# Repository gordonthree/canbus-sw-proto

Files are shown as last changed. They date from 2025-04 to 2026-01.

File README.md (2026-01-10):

# CAN bus switch prototype

Some circuit board sketches in the free version of EagleCad

## Brain board
* Raspberry Pi 3 or 4?
* Touchscreen usb + hdmi
* CAN bus to SPI shield
* Web based interface

## Alt brain board
* 1x ESP32
* 1x CAN bus transciever
* 1x 4-pos screw terminal for power + can
* 

## Demo 01 - Single switch with STM32 and CANBUS
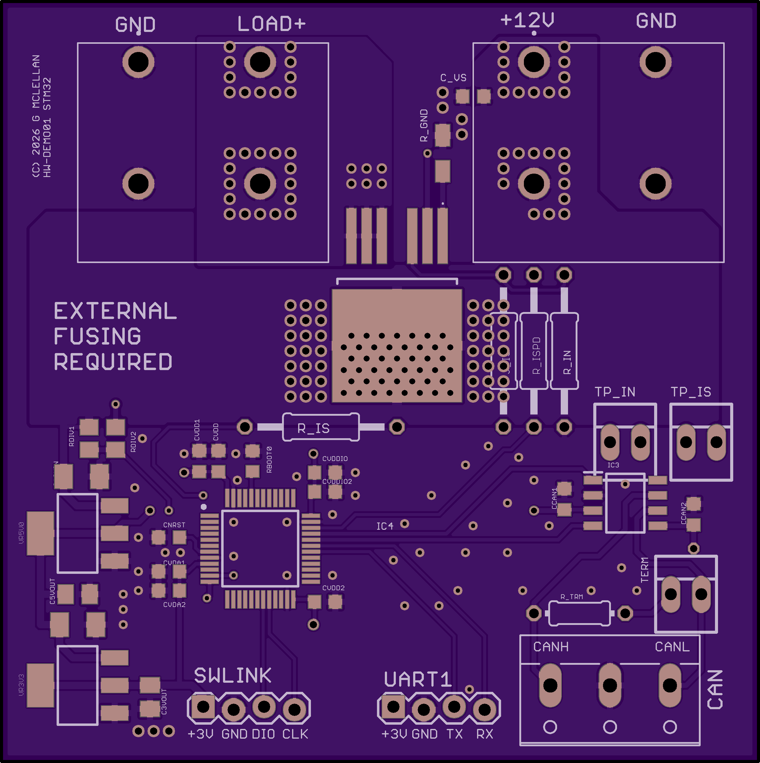
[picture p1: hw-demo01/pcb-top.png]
PCB rendering
* <br>
* 1x STM32F042
* 1x Isolated CAN bus transciever
* 1x Infineon BTS50010-1TAD PROFet Smart High Side Switch
* Voltage monitoring via resistor divider
* Current monitoring via Smart Switch
* Onboard 3v3 and 5v linear regulators
* Headers for SWLINK and UART
* Wago style screw terminal connector for 2-wire + drain CANBUS cable
* High current terminal block style battery input and load output
  
## Demo 02 - Single switch 
* 1x Infineon BTS50010-1TAD PROFet Smart High Side Switch
* Voltage monitoring via resistor divider
* Current monitoring via Smart Switch
* Header for control connection to microcontroller
* High current terminal block style battery input and load output

## Demo 03 - Dual switch with STM32 and CANBUS
* 1x STM32F042
* 1x Isolated CAN bus transciever
* 2x Infineon BTS50010-1TAD PROFet Smart High Side Switch
* Voltage monitoring via resistor divider
* Current monitoring via Smart Switch
* Onboard 3v3 and 5v linear regulators
* Headers for SWLINK and UART
* Wago style screw terminal connector for 2-wire + drain CANBUS cable
* High current terminal block style battery input and load output
  
## Prototype 01 Four switches
* 1x ESP32
* 1x CAN bus transciever
* 2x p-channel FETs (20a max?)
* 2x high side switch ICs (10a max?)
* 1x dual chan driver TC4472
* 1x 6-pos barrier strip V+ GND SW1 SW2 SW3 SW4
* 1x 3-pos terminal for can bus
* 1x serial programming header

## Prototype 02 Three switches
* 1x ESP32
* 1x CAN bus transciever
* 2x p-channel FETs (30a max?) power-so8
* 1x high side switch ICs (10a max?)
* 1x dual chan driver TC4472
* 1x 6-pos barrier strip V+ V+ SW1 SW2 SW3 GND
* 1x 3-pos terminal for can bus
* 1x serial programming header
  
## Prototype 03 Six switch
* 1x ESP32
* 1x CAN bus transciever
* 4x p-channel FETs (30a max?) power-so8
* 2x high side switch ICs (10a max?)
* 1x dual chan driver TC4472
* 1x 3-pos barrier strip for power +12 +12 GND
* 2x 6-pos barrier strip SW1 GND SW2 GND SW3 GND - repeated for other side
* 1x 3-pos terminal for can bus
* 1x serial programming header

## Prototype 04 Three switches with STM32
* 1x STM32F042C6
* 1x CAN bus transciever
* 2x p-channel FETs (30a max?) power-so8
* 1x high side switch ICs (10a max?)
* 1x dual chan driver TC4472
* 1x 6-pos barrier strip V+ V+ SW1 SW2 SW3 GND
* 1x 3-pos terminal for can bus
* 1x serial programming header
 
## Minimum interconnect for nodes
* 2-pair cable with drain
* first pair for CANH-IN and CANL-IN
* second pair for CANH-OUT and CANL-OUT
* drain is grounded at controller / hub

## Ideal interconnect for nodes
* 4-pair cable with drain
* first pair for CANH-IN and CANL-IN
* second and fourth pair for +VBAT and ground
* third pair for CANH-OUT and CANL-OUT
* drain is grounded at controller / hub

## CAN Hub
* eight total de9 connectors, one input, one output, six spurs
* each spur is wired in series, with Cx-IN and Cx-OUT daisy chained
* spurs that are not connected have a shorting plug installed connecting Cx-IN to Cx-OUT

## Parts
* 4x8 RGB matrix keypad https://www.adafruit.com/product/4020
* high side switch (ssr) https://mou.sr/4jcK616
* 6 position terminal block https://mou.sr/4i4P92Y
* heavy duty 6-pos terminal https://mou.sr/3R63QYn
* heavy duty 3-pos terminal block https://mou.sr/3FTFHBW
* ATO fuse holder https://mou.sr/4cihwsZ
* CANBUS Transceiver MCP2562T https://mou.sr/4llTLVa 
* ESP32 Module https://mou.sr/4j1XWDP
* Onboard DC-DC converter https://mou.sr/4i8eVTN
* P chan fet chonky https://mou.sr/42aUOja
* P chan power-so8 https://mou.sr/42BhcBs
* 3.3v LDO regulator https://mou.sr/3RgIUy6
* 20 awg shielded twisted pair cable https://a.co/d/8FQRYBL
* Texas Inst mosfet driver 5a inverted dual-ch SO8 https://mou.sr/3YqDYuk
* STM32 Micro with CAN bus 20 pin ssop https://mou.sr/4jwf9Fx
* ESP32 WROOM module with antenna https://mou.sr/3XWw2kl
* STM32 Dev Board using inexepensive mcu https://www.digikey.com/short/59jq87v5
* STM32 48-pin QFP STM32F042C6T7 https://mou.sr/3Eqjfjx
* DC-DC Switching regulator TPS560430 automotive 5v output https://mou.sr/4cZ1YLn
* DC-DC Sync-switching regulator LMR51625 automotive adjustable output https://mou.sr/4ipTHB4

## remote node introductions
* 10 seconds after boot remote nodes will start sending introduction messages 0x7XX
  * master will record message id and node id for each device
  * master will compare node id with database of known nodes
  * nodes that are already known will have their last-seen timestamp updated
  * newly introduced nodes will be added to the database, recording their first-seen timestamp
  * master will respond with 0x401 to the node to acknowledge introduction
  * after reciving 0x401 the remote node will clear the introduction flag and enter normal operation
* after no introductions the master will enumerate new nodes
  * master will send 0x402:0x40A to the remote node and nodes will respond with 0x710:0x74F for each module the node offers
  * modules will be recorded in database using unique 32-bit node ID and 16-bit module ID
  * master will send 0x401 to the remote node after recording each module 
* after introductions and enumeration master will review database of nodes
  * nodes with a timestamp older than the current boot timestamp will be marked as not-present
    * master will send 0x40C node check message to the node
    * if remote node responds with their node id, update last seen, flag for enumeration 
    * if remote node does not respond mark the node missing in the database and alert user

## normal operation
* after introduction and enumeration are complete master will send 0x10A indicating nodes should begin normal operation
* nodes start sending 0x5XX data messages at the configured rates

## request info flag
* master will instruct display module to request info, providing a message id
* display module will watch for the message id and receive 8 bytes of data

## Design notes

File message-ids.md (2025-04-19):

# CAN Bus Message IDs

Borrowed from [Kvaser](https://kvaser.com/can-protocol-tutorial/)
> ### A note on the Identifier Values
> We said that 11 (CAN 2.0A) or 29 (CAN 2.0B) bits is available in the Identifier. This is not entirely correct. Due to compability with a certain old CAN controller (guess which?), identifiers must not have the 7 most significant bits set to all ones, so only the identifiers 0..2031 are left for the 11-bit identifiers, and the user of 29-bit identifiers can use 532676608 different values. Note that all other CAN controllers accept the “illegal” identifiers, so in a modern CAN system identifiers 2032..2047 can be used without restrictions.

## We've moved
I'll make the link public readable eventually
* https://docs.google.com/spreadsheets/d/1QVM61p1eubtlPMyJ19RLGeI64S9uRlPBL7KCpJWwj3g/edit?gid=0#gid=0
  
### Notes
* https://docs.google.com/spreadsheets/d/1eirT8LbSRl4j06BpwgsiE4PM_2BGH9UStdWLXwKvHJw/edit?gid=10#gid=10

### Example
```
// Constants for specific message IDs (example)
#define ENGINE_TEMP_ID 0x100
#define VEHICLE_SPEED_ID 0x200
#define BATTERY_VOLTAGE_ID 0x300
```

Outdated info below.
## Priority 0 (should these be error frames?)
* 0x100: Over current
     * D0-D3: Device ID (unique)
     * D4-D5: Measured current 16-bits
* 0x110: Over temperature
     * D0-D3: Device ID (unique)
     * D4-D5: Measured temperature 16-bits
* 0x120: Over voltage
     * D0-D3: Device ID (unique)
     * D4-D5: Measured voltage 16-bits

## Priority 1
* 0x1A0: Set output switch state (on, off)
    * Bytes 0-3: Device ID (unique)
    * Byte 5: Switch number
    * Byte 6: Switch state
* 0x1B0: Set output switch mode (steady, blink, strobe, etc)
    * Bytes 0-3: Device ID (unique)
    * Byte 5: Switch number
    * Byte 6: Switch mode

## Priority 2
* 0x200: 

## Priority 3
* 0x300: 

## Priority 4
* 0x400:

## Priority 5
* 0x500:

## Priority 6
* 0x600:

## Priority 7
* 0x700: Device introduction
    * Bytes 0-3: Device ID (unique)
    * Byte 5: Device type (output switch, button panel, display, etc)
    * Byte 6: Device specific count (switches, buttons, etc)

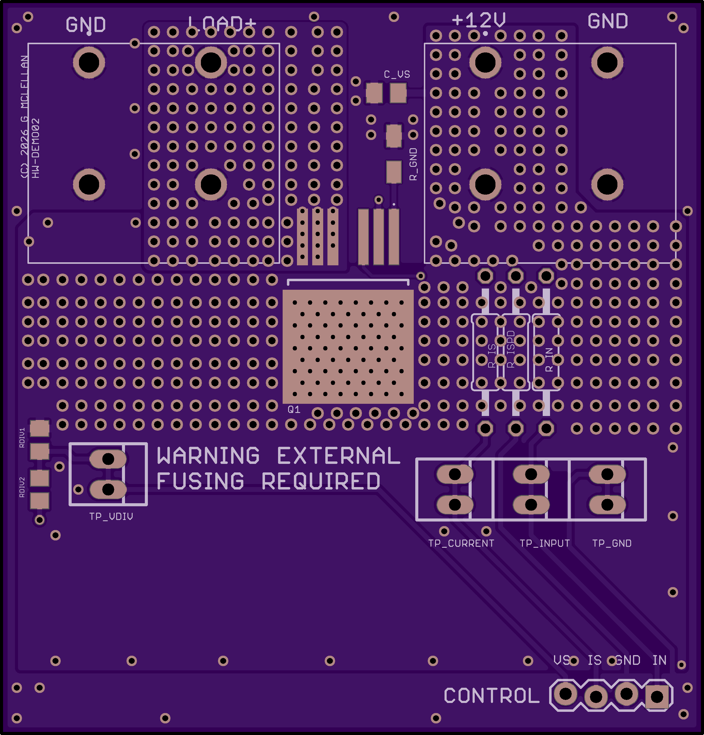
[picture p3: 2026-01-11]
hw-demo02/pcb-top-render-demo02.png

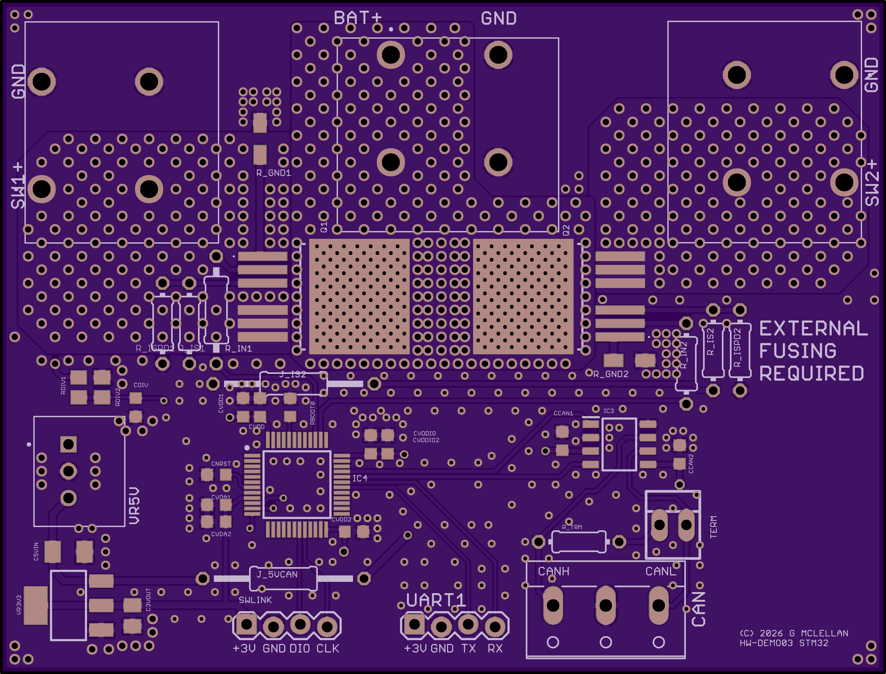
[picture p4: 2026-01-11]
hw-demo03/demo03-pcb-top.png

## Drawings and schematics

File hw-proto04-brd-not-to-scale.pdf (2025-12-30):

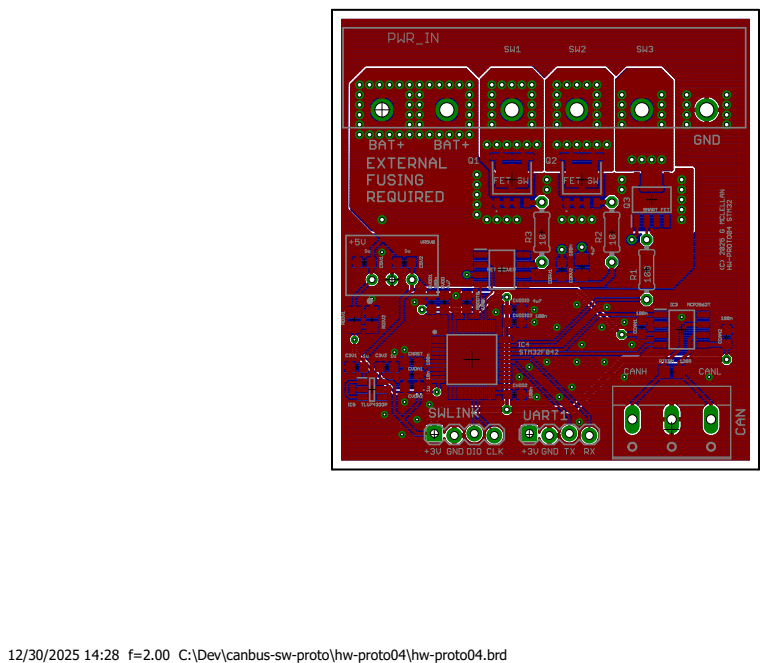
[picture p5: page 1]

12/30/2025 14:28 f=2.00 C:\Dev\canbus-sw-proto\hw-proto04\hw-proto04.brd

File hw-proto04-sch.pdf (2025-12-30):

A

A

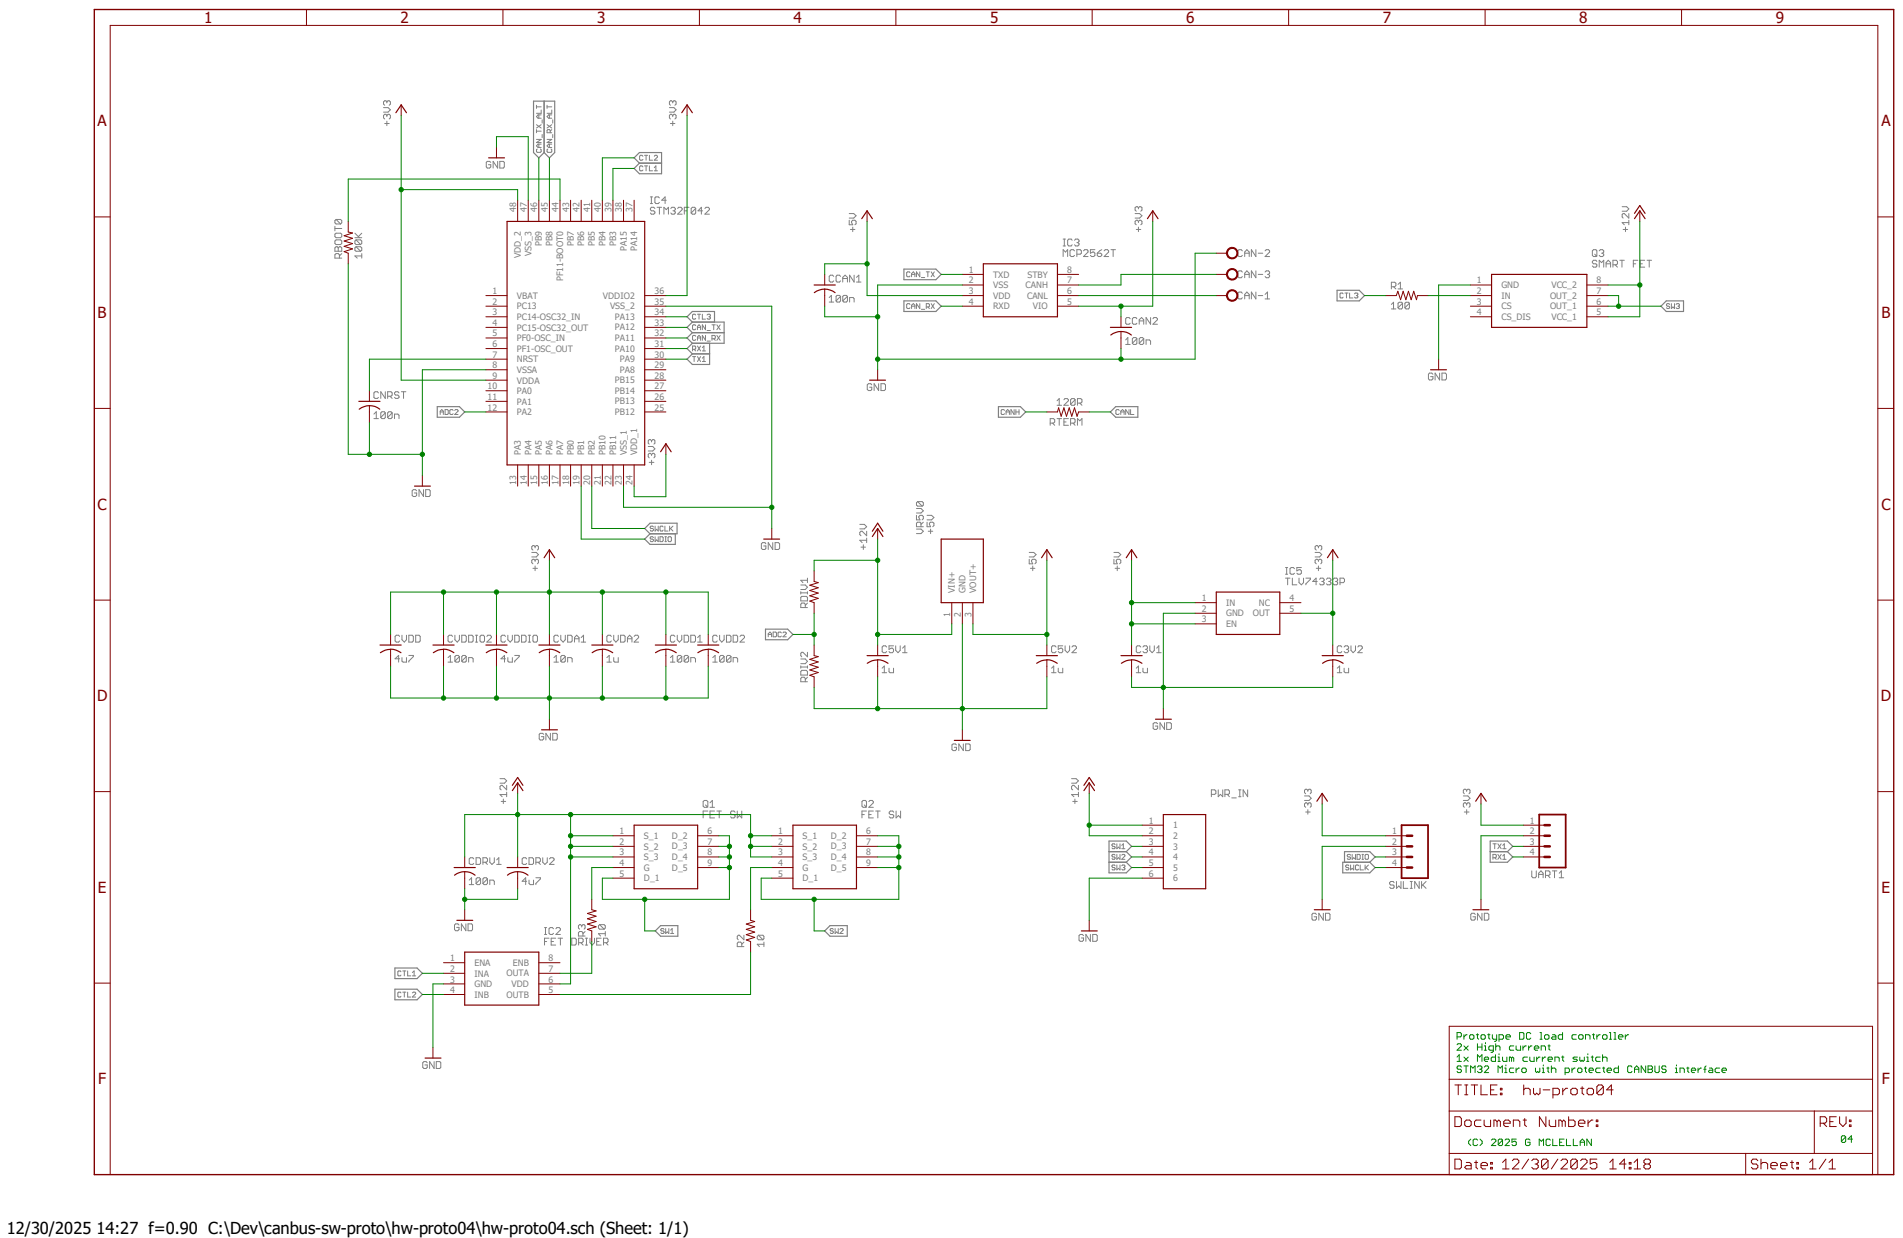
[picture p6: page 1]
GND 1; CS_DIS 4; VCC_2; 8 OUT_2; 7 OUT_1; 6 VCC_1; 5 TXD 1; VSS 2; VDD 3; RXD 4; STBY; 8 CANH; 7 CANL; 6 VIO; 6 VIN+ 1 GND; 2 VOUT+; 9 ENA 1; INA 2; GND 3; INB 4; ENB; 8 OUTA; 7 VDD; 6 OUTB; VBAT 1; PC14-OSC32_IN 3; PC15-OSC32_OUT 4; PF0-OSC_IN 5; PF1-OSC_OUT 6; NRST 7; VSSA 8; VDDA 9; PA³ 13 PA⁴ 14 PA⁵ 15 PA⁶ 16 PA⁷ 17 PB0 18 PB1 19 PB2 20 PB10 21 PB11 22 VSS_1 23 VDD_1 24 VDDIO2; 36 VSS_2; 25 VDD_2 48 VSS_3 47 PB9 46 PB8 45 PF11⁻BOOT0 44 PB7 43 PB6 42 PB5 41 PB4 40 PB3 39 PA¹⁵ ³⁸ PA¹⁴ ³⁷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

12/30/2025 14:27 f=0.90 C:\Dev\canbus-sw-proto\hw-proto04\hw-proto04.sch (Sheet: 1/1)

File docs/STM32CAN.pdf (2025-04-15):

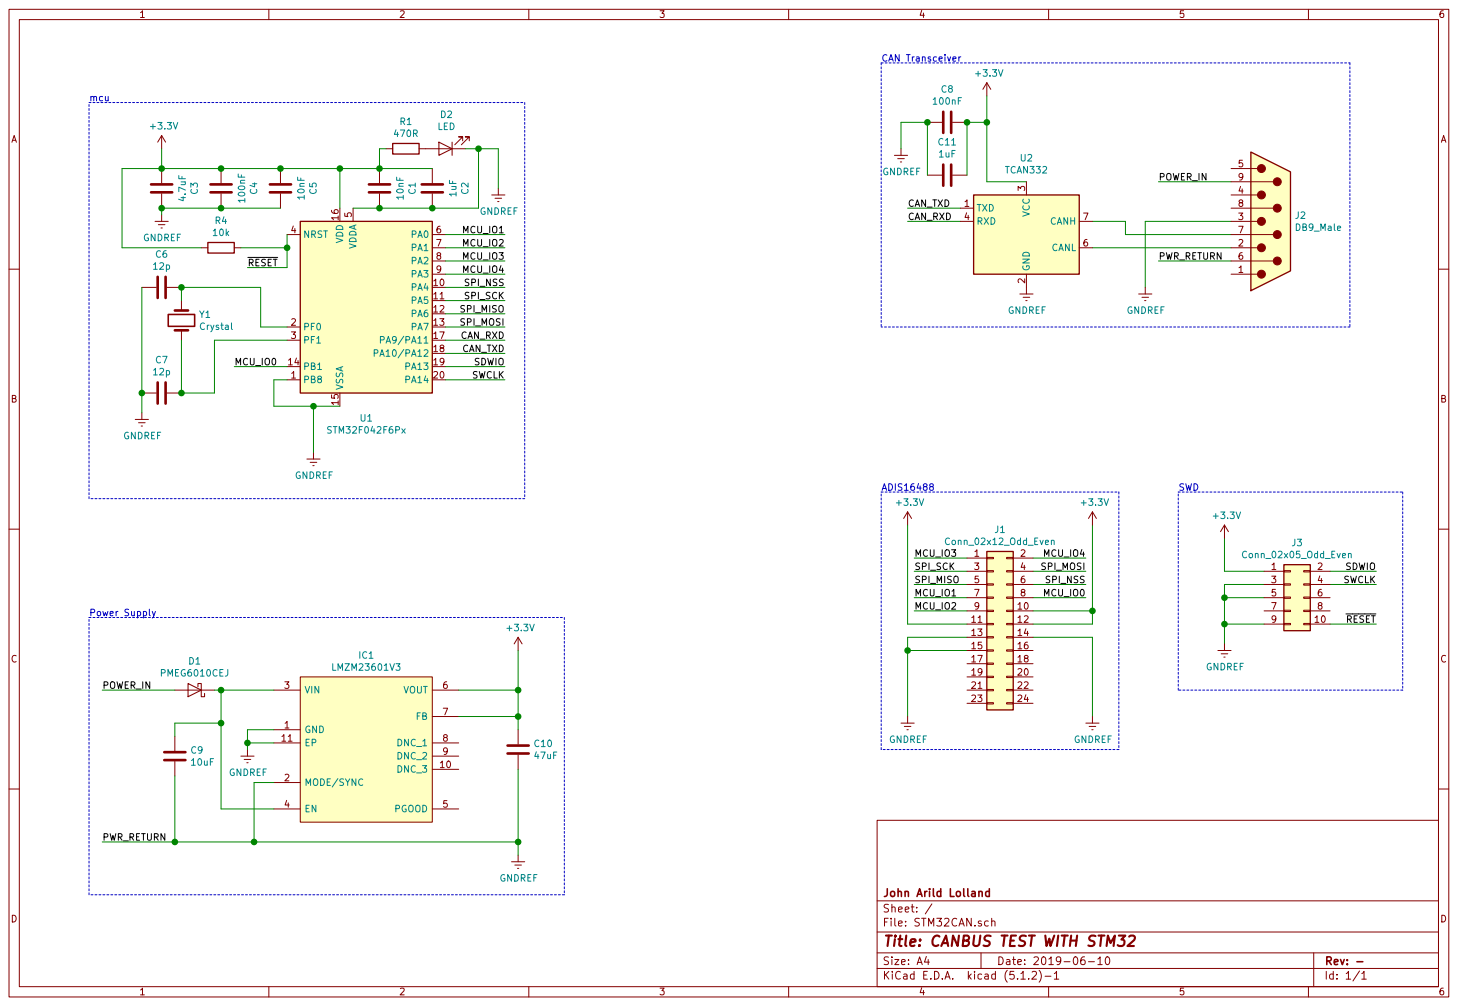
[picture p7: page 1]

3 RXD 4 CANL 6 CANH 7 U2 TCAN332 SWD

File: STM32CAN.sch Sheet: / John Arild Lolland

Id: 1/1 Title: CANBUS TEST WITH STM32

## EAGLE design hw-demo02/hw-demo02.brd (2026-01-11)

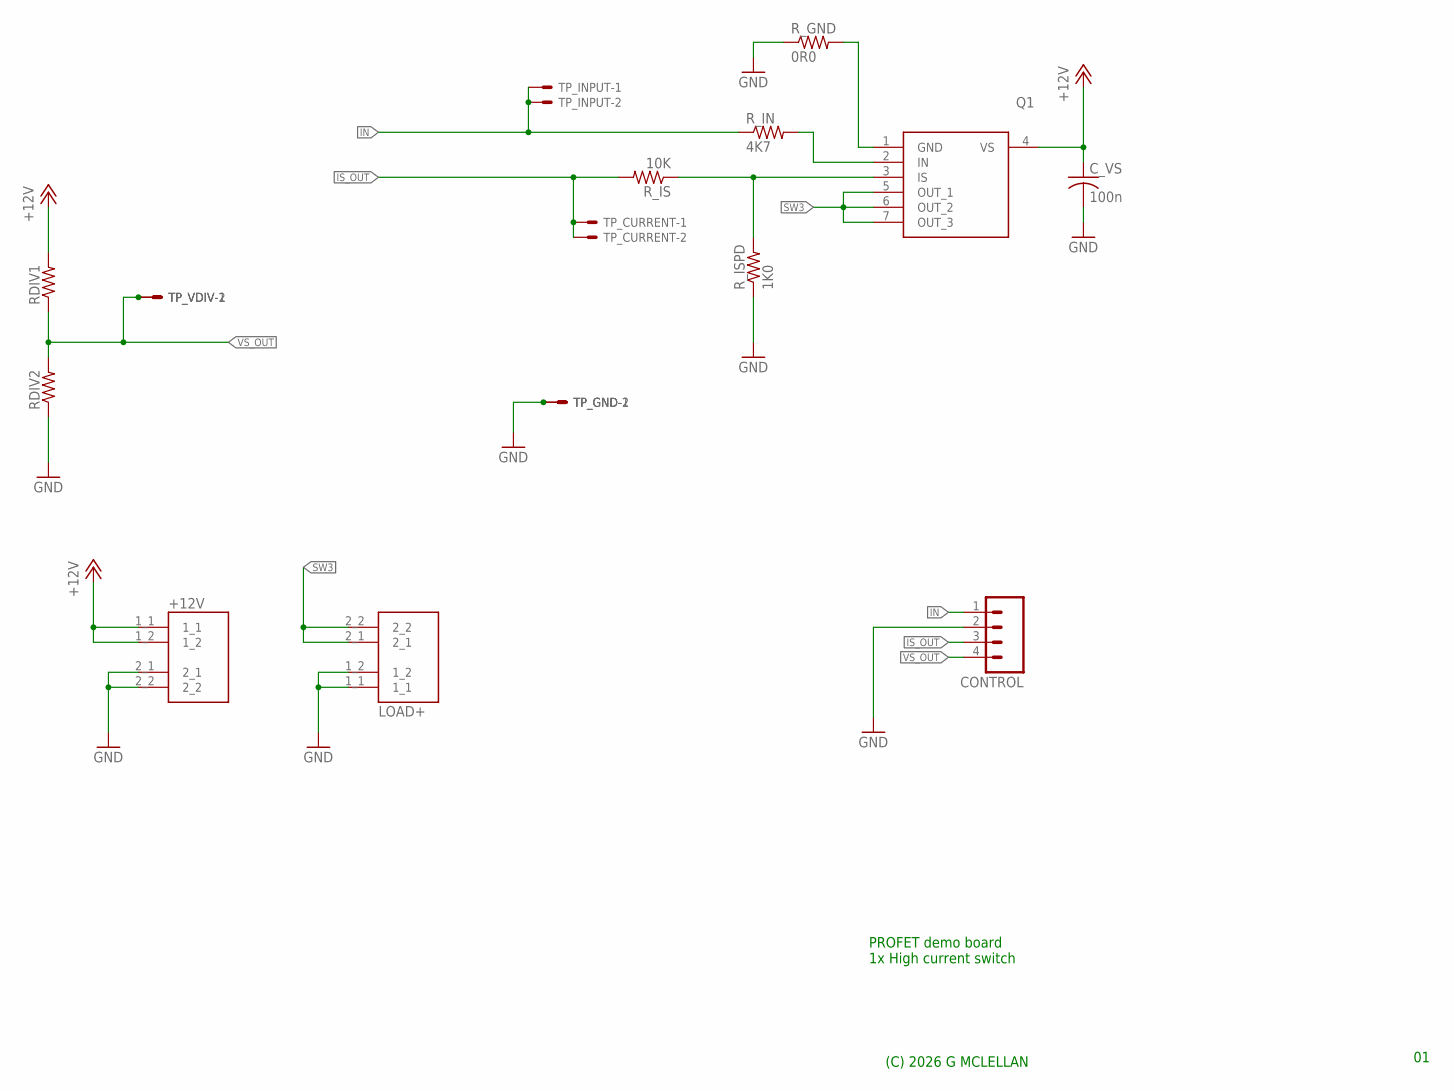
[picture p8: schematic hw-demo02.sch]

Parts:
+12V: VP0265840000G; AMPHENOL_VP0265840000G
CONTROL: M04LOCK; 1X04_LOCK
C_VS: 100n; C0805K
LOAD+: VP0265840000G; AMPHENOL_VP0265840000G
Q1: BTS500101TADATMA2
RDIV1, RDIV2: R-US_R0805; R0805
R_GND: 0R0; R1206W
R_IN: 4K7; 0207/12
R_IS: 10K; 0207/12
R_ISPD: 1K0; 0207/12
TP_CURRENT: 22-23-2021
TP_GND: 22-23-2021
TP_INPUT: 22-23-2021
TP_VDIV: 22-23-2021

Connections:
+12V: +12V.1_1, +12V.1_2, C_VS.1, Q1.4 (VS), RDIV1.2
CTL3`: Q1.2 (IN), R_IN.2
GND: +12V.2_1, +12V.2_2, CONTROL.2, C_VS.2, LOAD+.1_1, LOAD+.1_2, RDIV2.1, R_GND.1, R_ISPD.1, TP_GND.1, TP_GND.2
IN: CONTROL.1, R_IN.1, TP_INPUT.1, TP_INPUT.2
IS: Q1.3 (IS), R_IS.1, R_ISPD.2
IS_OUT: CONTROL.3, R_IS.2, TP_CURRENT.1, TP_CURRENT.2
unnamed: Q1.1 (GND), R_GND.2
SW3: LOAD+.2_1, LOAD+.2_2, Q1.5 (OUT_1), Q1.6 (OUT_2), Q1.7 (OUT_3)
VS_OUT: CONTROL.4, RDIV1.1, RDIV2.2, TP_VDIV.1, TP_VDIV.2

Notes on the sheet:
PROFET demo board 1x High current switch
(C) 2026 G MCLELLAN

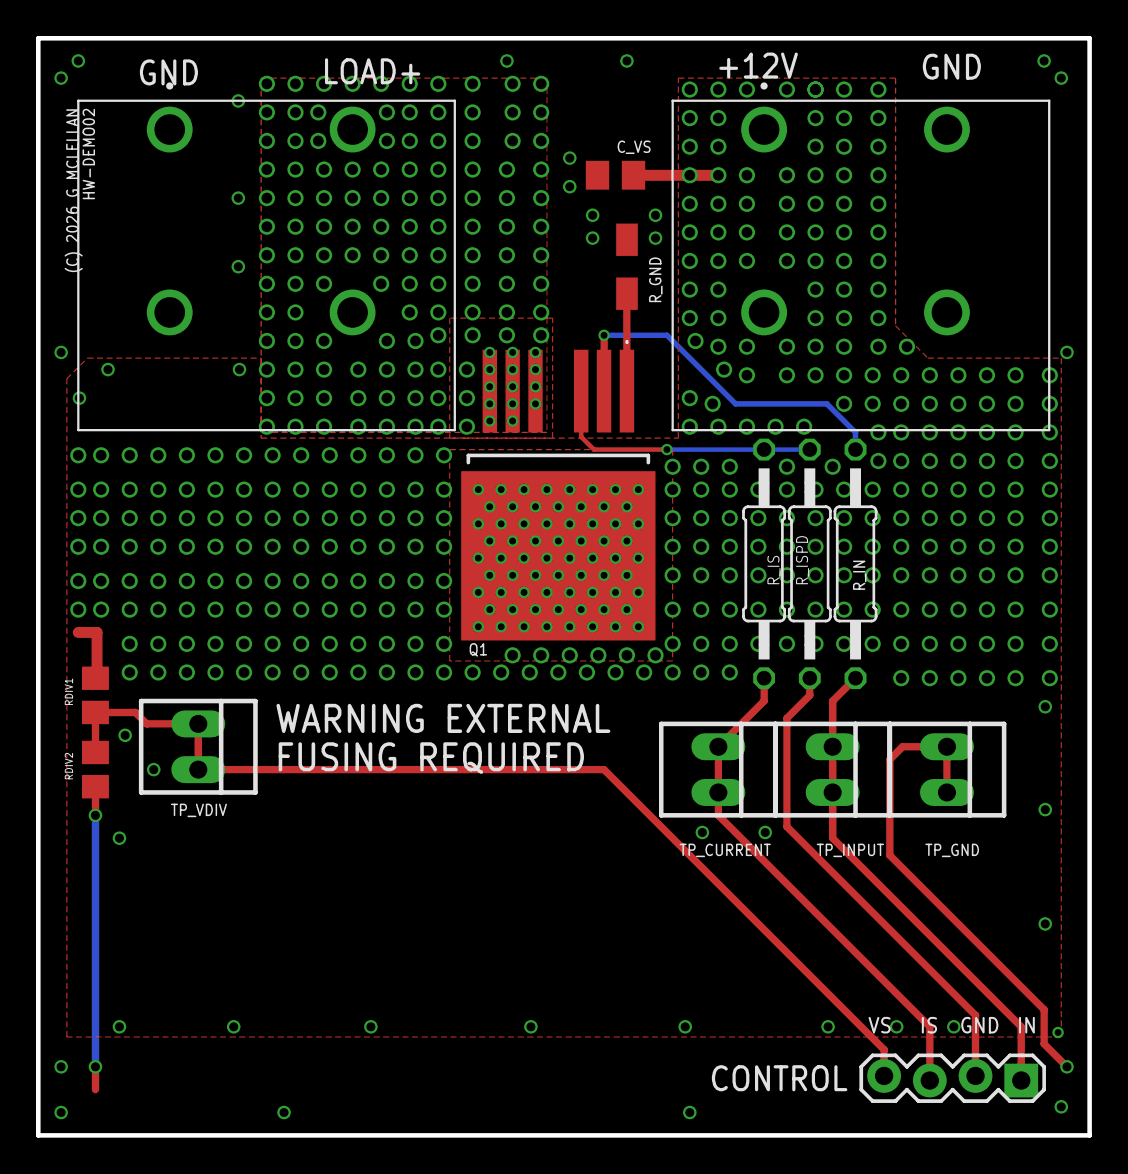
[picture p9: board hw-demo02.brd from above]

Board: 2 copper layers, 58.4 x 61.0 mm, 15 parts (0 on the bottom side), 9 nets.

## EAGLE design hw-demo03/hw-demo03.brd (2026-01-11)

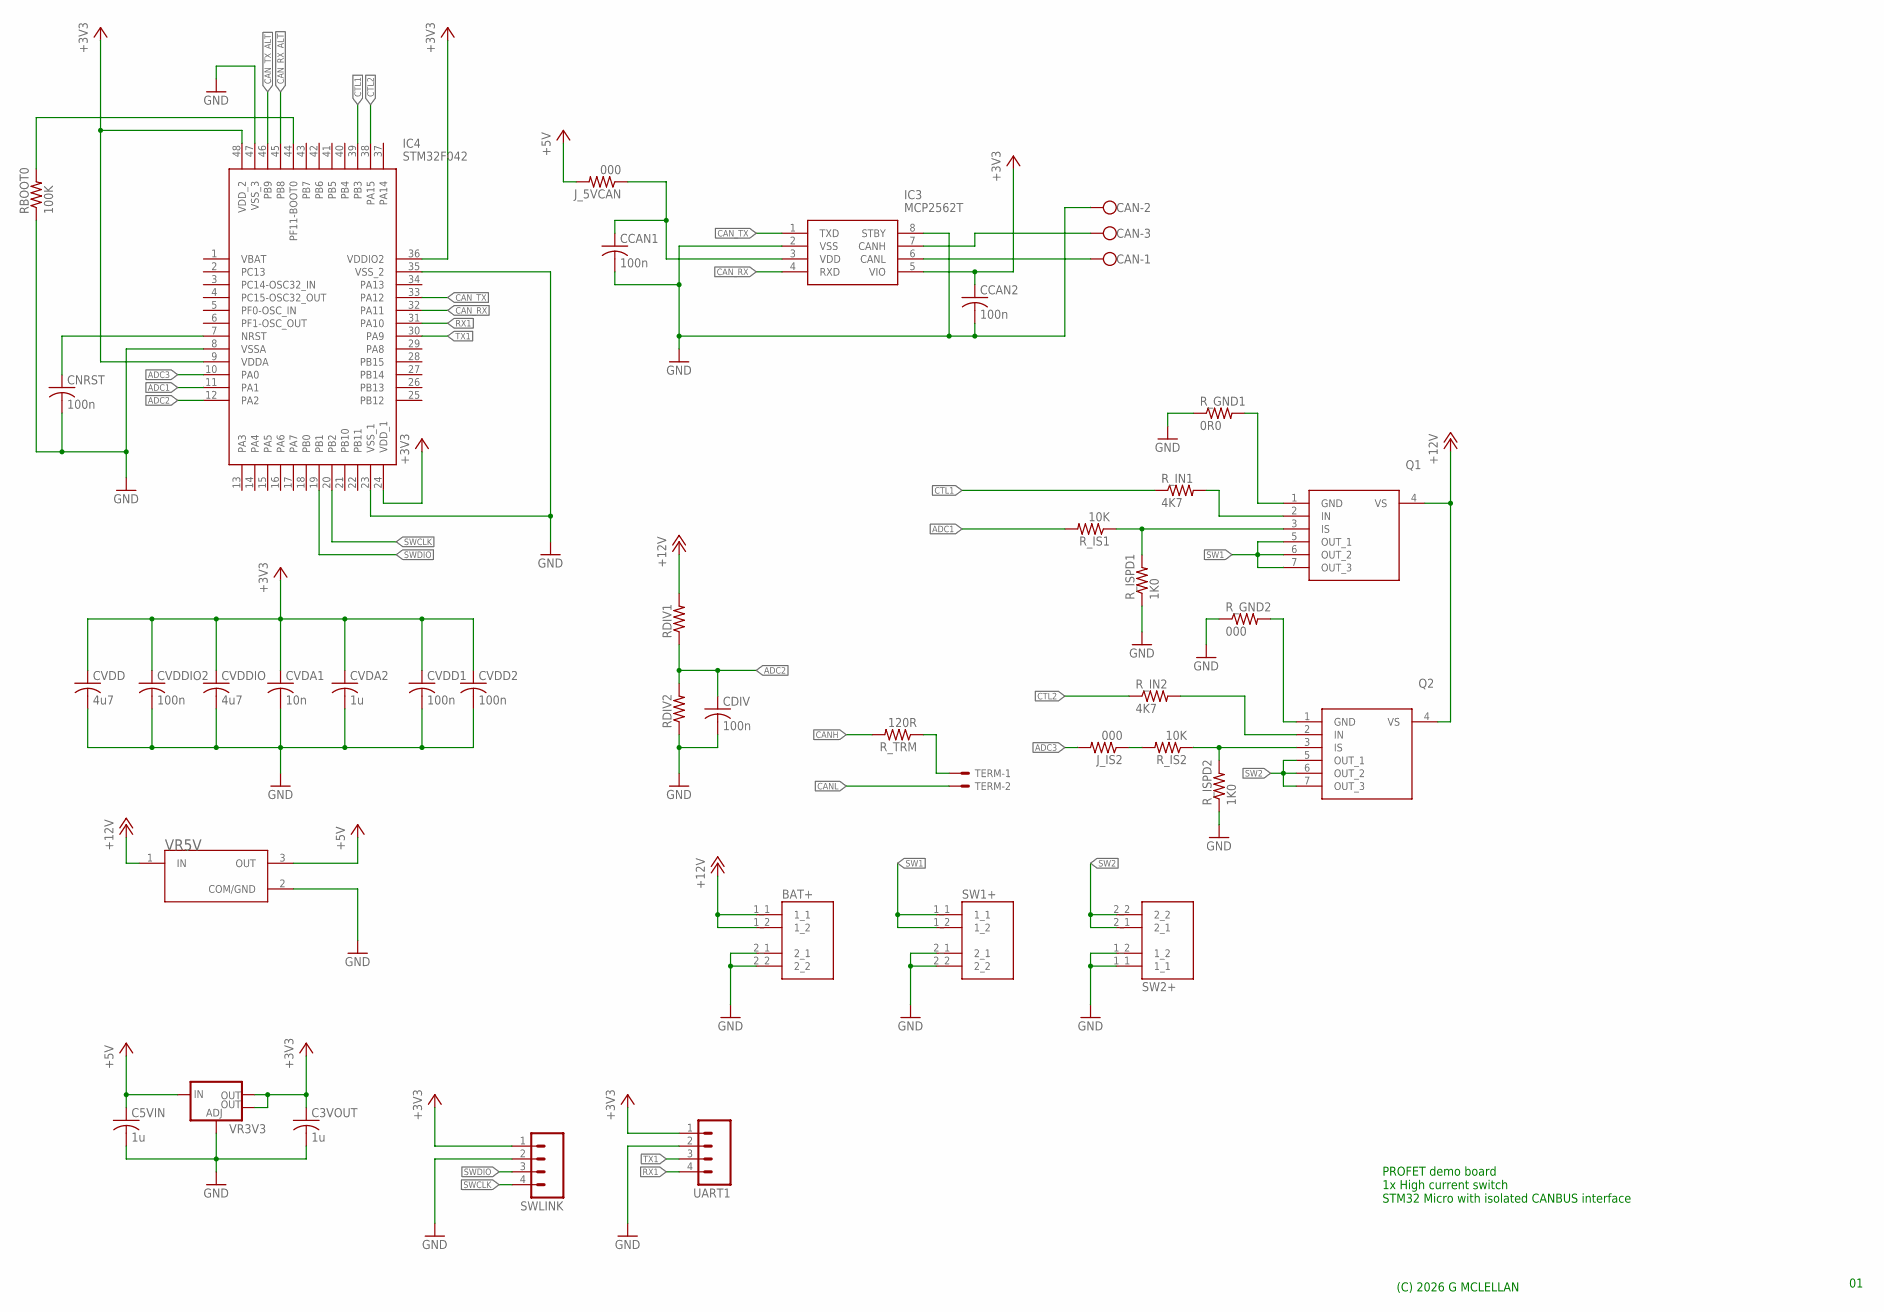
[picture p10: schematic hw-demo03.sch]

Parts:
BAT+: VP0265840000G; AMPHENOL_VP0265840000G
C3VOUT: 1u; C0805K
C5VIN: 1u; C1206K
CAN: W237-103
CCAN1, CCAN2: 100n; C0603K
CDIV: 100n; C0603K
CNRST: 100n; C0603K
CVDA1: 10n; C0603K
CVDA2: 1u; C0603K
CVDD: 4u7; C0603K
CVDD1, CVDD2: 100n; C0603K
CVDDIO: 4u7; C0603K
CVDDIO2: 100n; C0603K
IC3: MCP2562T; SOIC127P600X175-8N
IC4: STM32F042; QFP50P900X900X160-48N
J_5VCAN: 000; 0207/15
J_IS2: 000; 0207/15
Q1, Q2: BTS500101TADATMA2
RBOOT0: 100K; R0603
RDIV1, RDIV2: R-US_R0805; R0805
R_GND1: 0R0; R1206W
R_GND2: 000; R1206W
R_IN1: 4K7; 0207/10
R_IN2: 4K7; 0204/7
R_IS1, R_IS2: 10K; 0204/7
R_ISPD1, R_ISPD2: 1K0; 0204/7
R_TRM: 120R; 0204/7
SW1+, SW2+: VP0265840000G; AMPHENOL_VP0265840000G
SWLINK: M04LOCK; 1X04_LOCK
TERM: 22-23-2021
UART1: M04LOCK; 1X04_LOCK
VR3V3: V_REG_LM1117SOT223; SOT223
VR5V: OKI-78SR-5/1.5-W36-C; CONV_OKI-78SR-5/1.5-W36-C

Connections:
+3V3: C3VOUT.1, CCAN2.1, CVDA1.1, CVDA2.1, CVDD.1, CVDD1.1, CVDD2.1, CVDDIO.1, CVDDIO2.1, IC3.5 (VIO), IC4.9 (VDDA), IC4.24 (VDD_1), IC4.36 (VDDIO2), IC4.48 (VDD_2), SWLINK.1, UART1.1, VR3V3.2 (OUT), VR3V3.4 (OUT)
+5V: C5VIN.1, J_5VCAN.2, VR3V3.3 (IN), VR5V.3 (OUT)
+12V: BAT+.1_1, BAT+.1_2, Q1.4 (VS), Q2.4 (VS), RDIV1.2, VR5V.1 (IN)
ADC1: IC4.11 (PA1), R_IS1.2
ADC2: CDIV.1, IC4.12 (PA2), RDIV1.1, RDIV2.2
ADC3: IC4.10 (PA0), J_IS2.2
BOOT0: IC4.44 (PF11-BOOT0), RBOOT0.2
CANH: CAN.3, IC3.7 (CANH), R_TRM.2
CANL: CAN.1, IC3.6 (CANL), TERM.2
CAN_RX: IC3.4 (RXD), IC4.32 (PA11)
CAN_RX_ALT: IC4.45 (PB8)
CAN_TX: IC3.1 (TXD), IC4.33 (PA12)
CAN_TX_ALT: IC4.46 (PB9)
CTL1: IC4.39 (PB3), R_IN1.1
CTL2: IC4.38 (PA15), R_IN2.1
CTL3`: Q1.2 (IN), R_IN1.2
GND: BAT+.2_1, BAT+.2_2, C3VOUT.2, C5VIN.2, CAN.2, CCAN1.2, CCAN2.2, CDIV.2, CNRST.2, CVDA1.2, CVDA2.2, CVDD.2, CVDD1.2, CVDD2.2, CVDDIO.2, CVDDIO2.2, IC3.2 (VSS), IC3.8 (STBY), IC4.8 (VSSA), IC4.23 (VSS_1), IC4.35 (VSS_2), IC4.47 (VSS_3), RBOOT0.1, RDIV2.1, R_GND1.1, R_GND2.1, R_ISPD1.1, R_ISPD2.1, SW1+.2_1, SW1+.2_2, SW2+.1_1, SW2+.1_2, SWLINK.2, UART1.2, VR3V3.1 (ADJ), VR5V.2 (COM/GND)
IS: Q1.3 (IS), R_IS1.1, R_ISPD1.2
unnamed: R_TRM.1, TERM.1
unnamed: J_IS2.1, R_IS2.2
unnamed: Q1.1 (GND), R_GND1.2
unnamed: Q2.1 (GND), R_GND2.2
unnamed: Q2.2 (IN), R_IN2.2
unnamed: Q2.3 (IS), R_IS2.1, R_ISPD2.2
unnamed: CCAN1.1, IC3.3 (VDD), J_5VCAN.1
unnamed: CNRST.1, IC4.7 (NRST)
RX1: IC4.31 (PA10), UART1.4
SW1: Q1.5 (OUT_1), Q1.6 (OUT_2), Q1.7 (OUT_3), SW1+.1_1, SW1+.1_2
SW2: Q2.5 (OUT_1), Q2.6 (OUT_2), Q2.7 (OUT_3), SW2+.2_1, SW2+.2_2
SWCLK: IC4.20 (PB2), SWLINK.4
SWDIO: IC4.19 (PB1), SWLINK.3
TX1: IC4.30 (PA9), UART1.3

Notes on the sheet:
PROFET demo board 1x High current switch STM32 Micro with isolated CANBUS interface
(C) 2026 G MCLELLAN

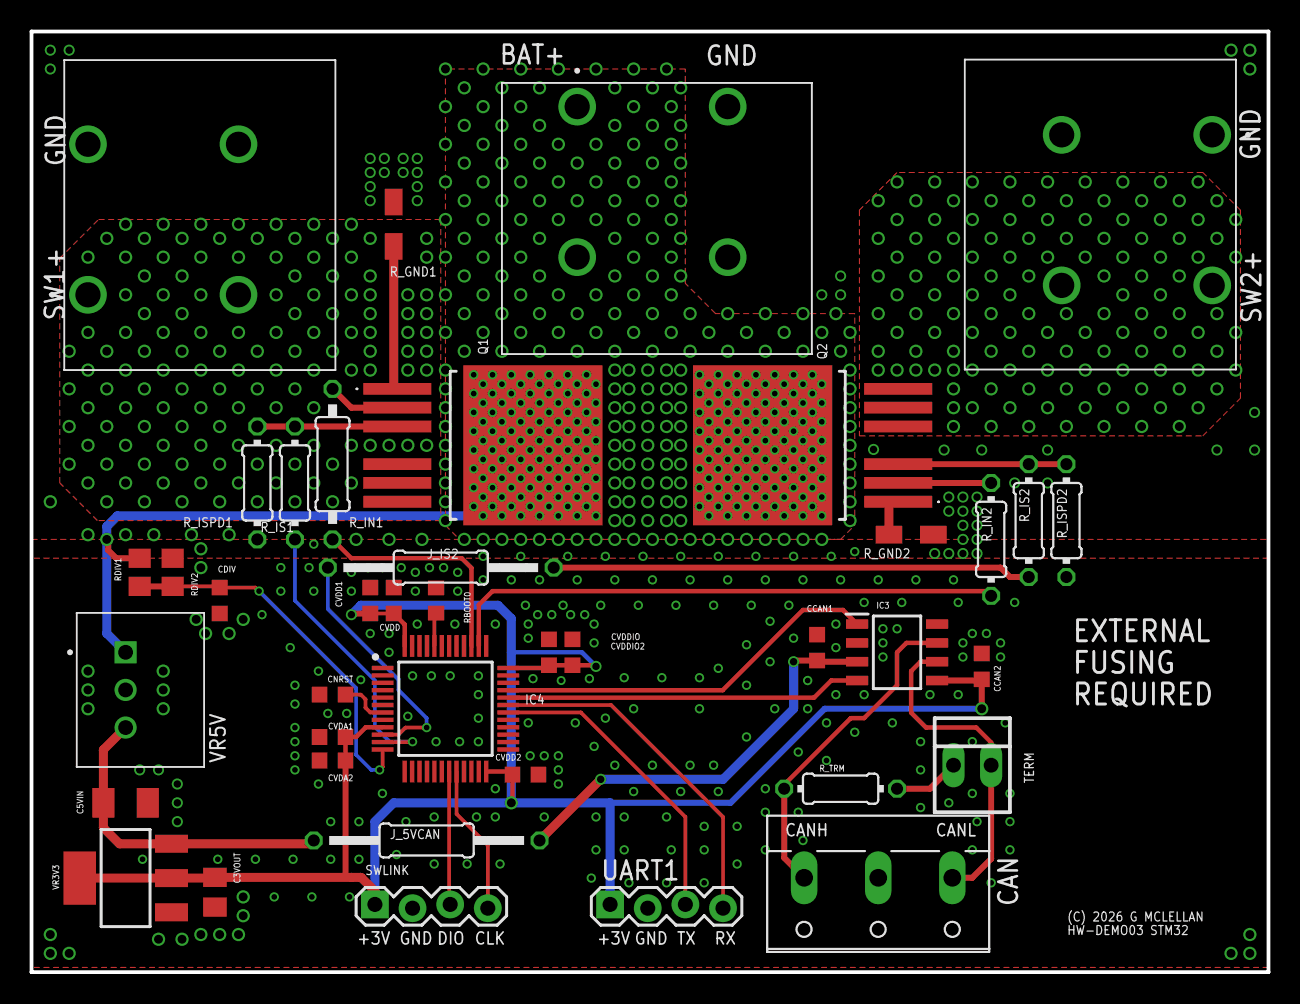
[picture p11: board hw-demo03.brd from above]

Board: 2 copper layers, 83.5 x 63.5 mm, 40 parts (0 on the bottom side), 30 nets.

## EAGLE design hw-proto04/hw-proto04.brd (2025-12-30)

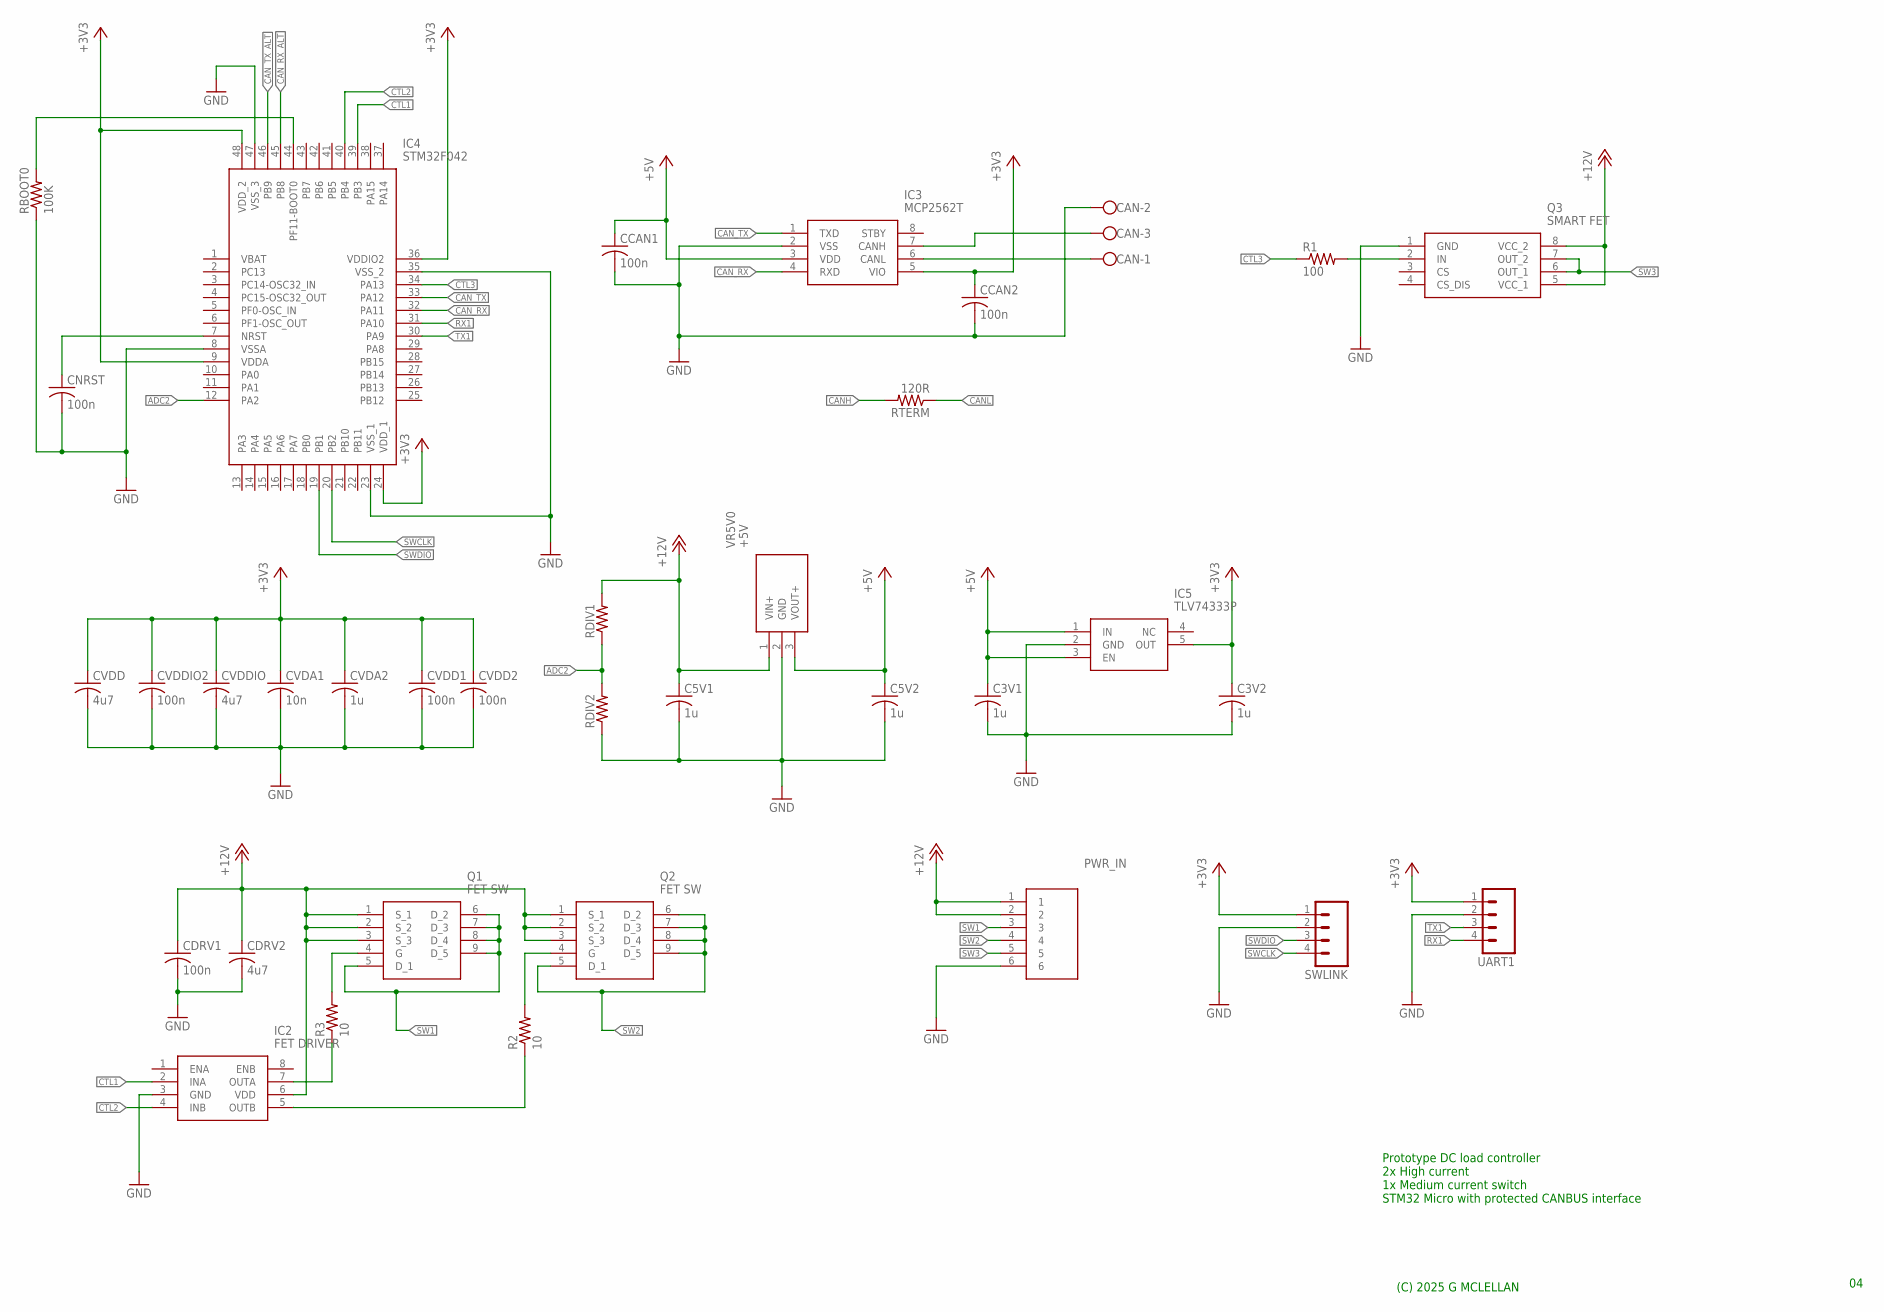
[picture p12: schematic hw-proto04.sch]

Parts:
C3V1, C3V2, C5V1, C5V2: 1u; C0603K
CAN: W237-103
CCAN1, CCAN2: 100n; C0603K
CDRV1: 100n; C0603K
CDRV2: 4u7; C0805K
CNRST: 100n; C0603K
CVDA1: 10n; C0603K
CVDA2: 1u; C0603K
CVDD: 4u7; C0603K
CVDD1, CVDD2: 100n; C0603K
CVDDIO: 4u7; C0603K
CVDDIO2: 100n; C0603K
IC2: FET DRIVER; SOIC127P600X175-8N
IC3: MCP2562T; SOIC127P600X175-8N
IC4: STM32F042; QFP50P900X900X160-48N
IC5: TLV74333P; SOT95P280X145-5N
PWR_IN: 4DB-P108-06; 4DBP10806
Q1, Q2: FET SW; SQJ147ELPT1_GE3
Q3: SMART FET; SOIC127P600X175-8N
R1: 100; 0204/7
R2, R3: 10; 0204/7
RBOOT0: 100K; R0603
RDIV1, RDIV2: R-US_R0805; R0805
RTERM: 120R; R0805
SWLINK: M04LOCK; 1X04_LOCK
UART1: M04LOCK; 1X04_LOCK
VR5V0: +5V; TSR-1-2433

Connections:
+3V3: C3V2.1, CCAN2.1, CVDA1.1, CVDA2.1, CVDD.1, CVDD1.1, CVDD2.1, CVDDIO.1, CVDDIO2.1, IC3.5 (VIO), IC4.9 (VDDA), IC4.24 (VDD_1), IC4.36 (VDDIO2), IC4.48 (VDD_2), IC5.5 (OUT), SWLINK.1, UART1.1
+5V: C3V1.1, C5V2.1, CCAN1.1, IC3.3 (VDD), IC5.1 (IN), IC5.3 (EN), VR5V0.3 (VOUT+)
+12V: C5V1.1, CDRV1.1, CDRV2.1, IC2.6 (VDD), PWR_IN.1, PWR_IN.2, Q1.1 (S_1), Q1.2 (S_2), Q1.3 (S_3), Q2.1 (S_1), Q2.2 (S_2), Q2.3 (S_3), Q3.5 (VCC_1), Q3.8 (VCC_2), RDIV1.2, VR5V0.1 (VIN+)
ADC2: IC4.12 (PA2), RDIV1.1, RDIV2.2
BOOT0: IC4.44 (PF11-BOOT0), RBOOT0.2
CANH: CAN.3, IC3.7 (CANH), RTERM.2
CANL: CAN.1, IC3.6 (CANL), RTERM.1
CAN_RX: IC3.4 (RXD), IC4.32 (PA11)
CAN_RX_ALT: IC4.45 (PB8)
CAN_TX: IC3.1 (TXD), IC4.33 (PA12)
CAN_TX_ALT: IC4.46 (PB9)
CTL1: IC2.2 (INA), IC4.39 (PB3)
CTL2: IC2.4 (INB), IC4.40 (PB4)
CTL3: IC4.34 (PA13), R1.1
GND: C3V1.2, C3V2.2, C5V1.2, C5V2.2, CAN.2, CCAN1.2, CCAN2.2, CDRV1.2, CDRV2.2, CNRST.2, CVDA1.2, CVDA2.2, CVDD.2, CVDD1.2, CVDD2.2, CVDDIO.2, CVDDIO2.2, IC2.3 (GND), IC3.2 (VSS), IC4.8 (VSSA), IC4.23 (VSS_1), IC4.35 (VSS_2), IC4.47 (VSS_3), IC5.2 (GND), PWR_IN.6, Q3.1 (GND), RBOOT0.1, RDIV2.1, SWLINK.2, UART1.2, VR5V0.2 (GND)
unnamed: IC2.5 (OUTB), R2.1
unnamed: IC2.7 (OUTA), R3.1
unnamed: Q1.4 (G), R3.2
unnamed: Q2.4 (G), R2.2
unnamed: Q3.2 (IN), R1.2
unnamed: CNRST.1, IC4.7 (NRST)
RX1: IC4.31 (PA10), UART1.4
SW1: PWR_IN.3, Q1.5 (D_1), Q1.6 (D_2), Q1.7 (D_3), Q1.8 (D_4), Q1.9 (D_5)
SW2: PWR_IN.4, Q2.5 (D_1), Q2.6 (D_2), Q2.7 (D_3), Q2.8 (D_4), Q2.9 (D_5)
SW3: PWR_IN.5, Q3.6 (OUT_1), Q3.7 (OUT_2)
SWCLK: IC4.20 (PB2), SWLINK.4
SWDIO: IC4.19 (PB1), SWLINK.3
TX1: IC4.30 (PA9), UART1.3

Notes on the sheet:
Prototype DC load controller 2x High current 1x Medium current switch STM32 Micro with protected CANBUS interface
(C) 2025 G MCLELLAN

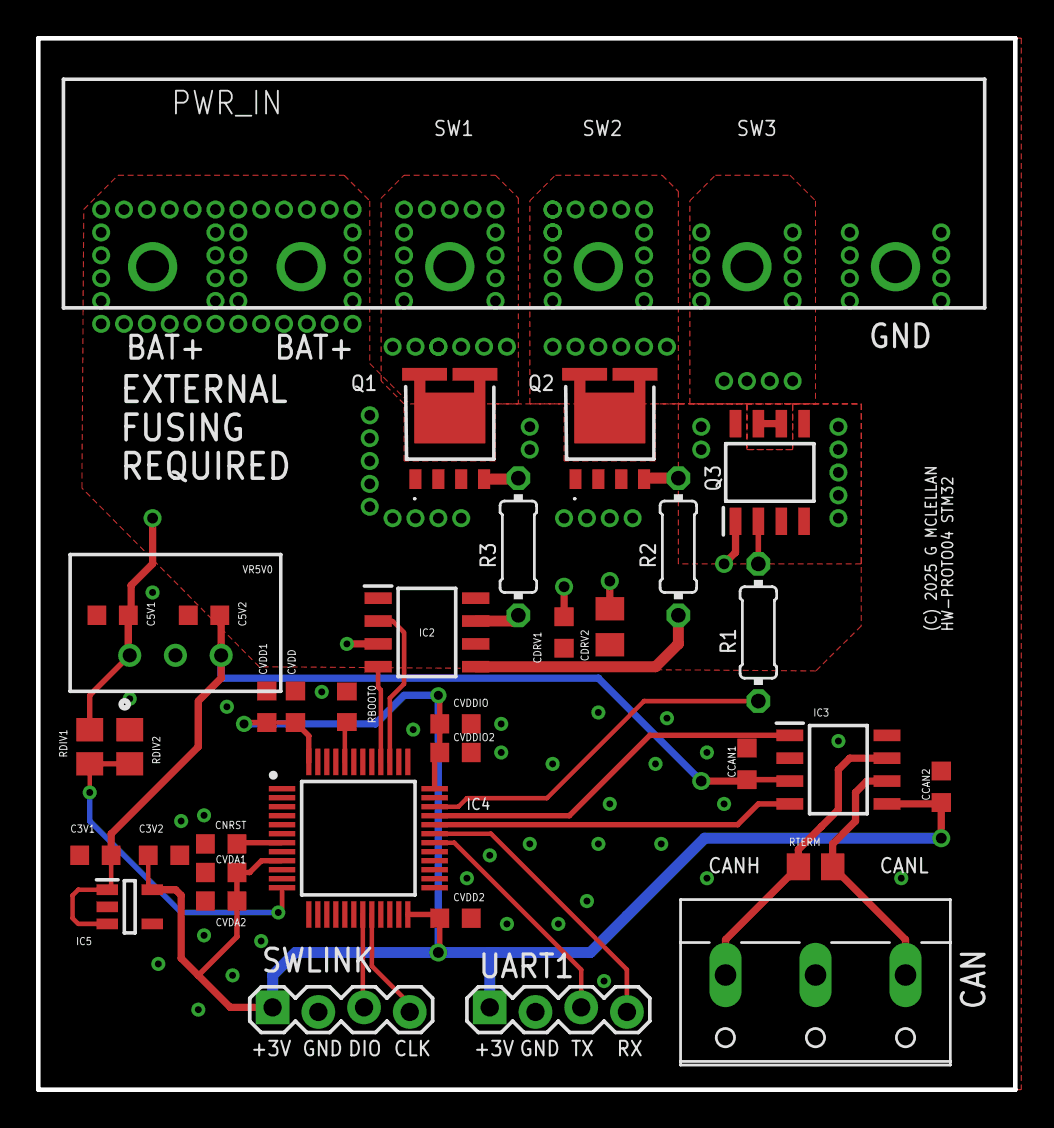
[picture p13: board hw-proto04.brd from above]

Board: 2 copper layers, 54.3 x 58.4 mm, 35 parts (0 on the bottom side), 26 nets.

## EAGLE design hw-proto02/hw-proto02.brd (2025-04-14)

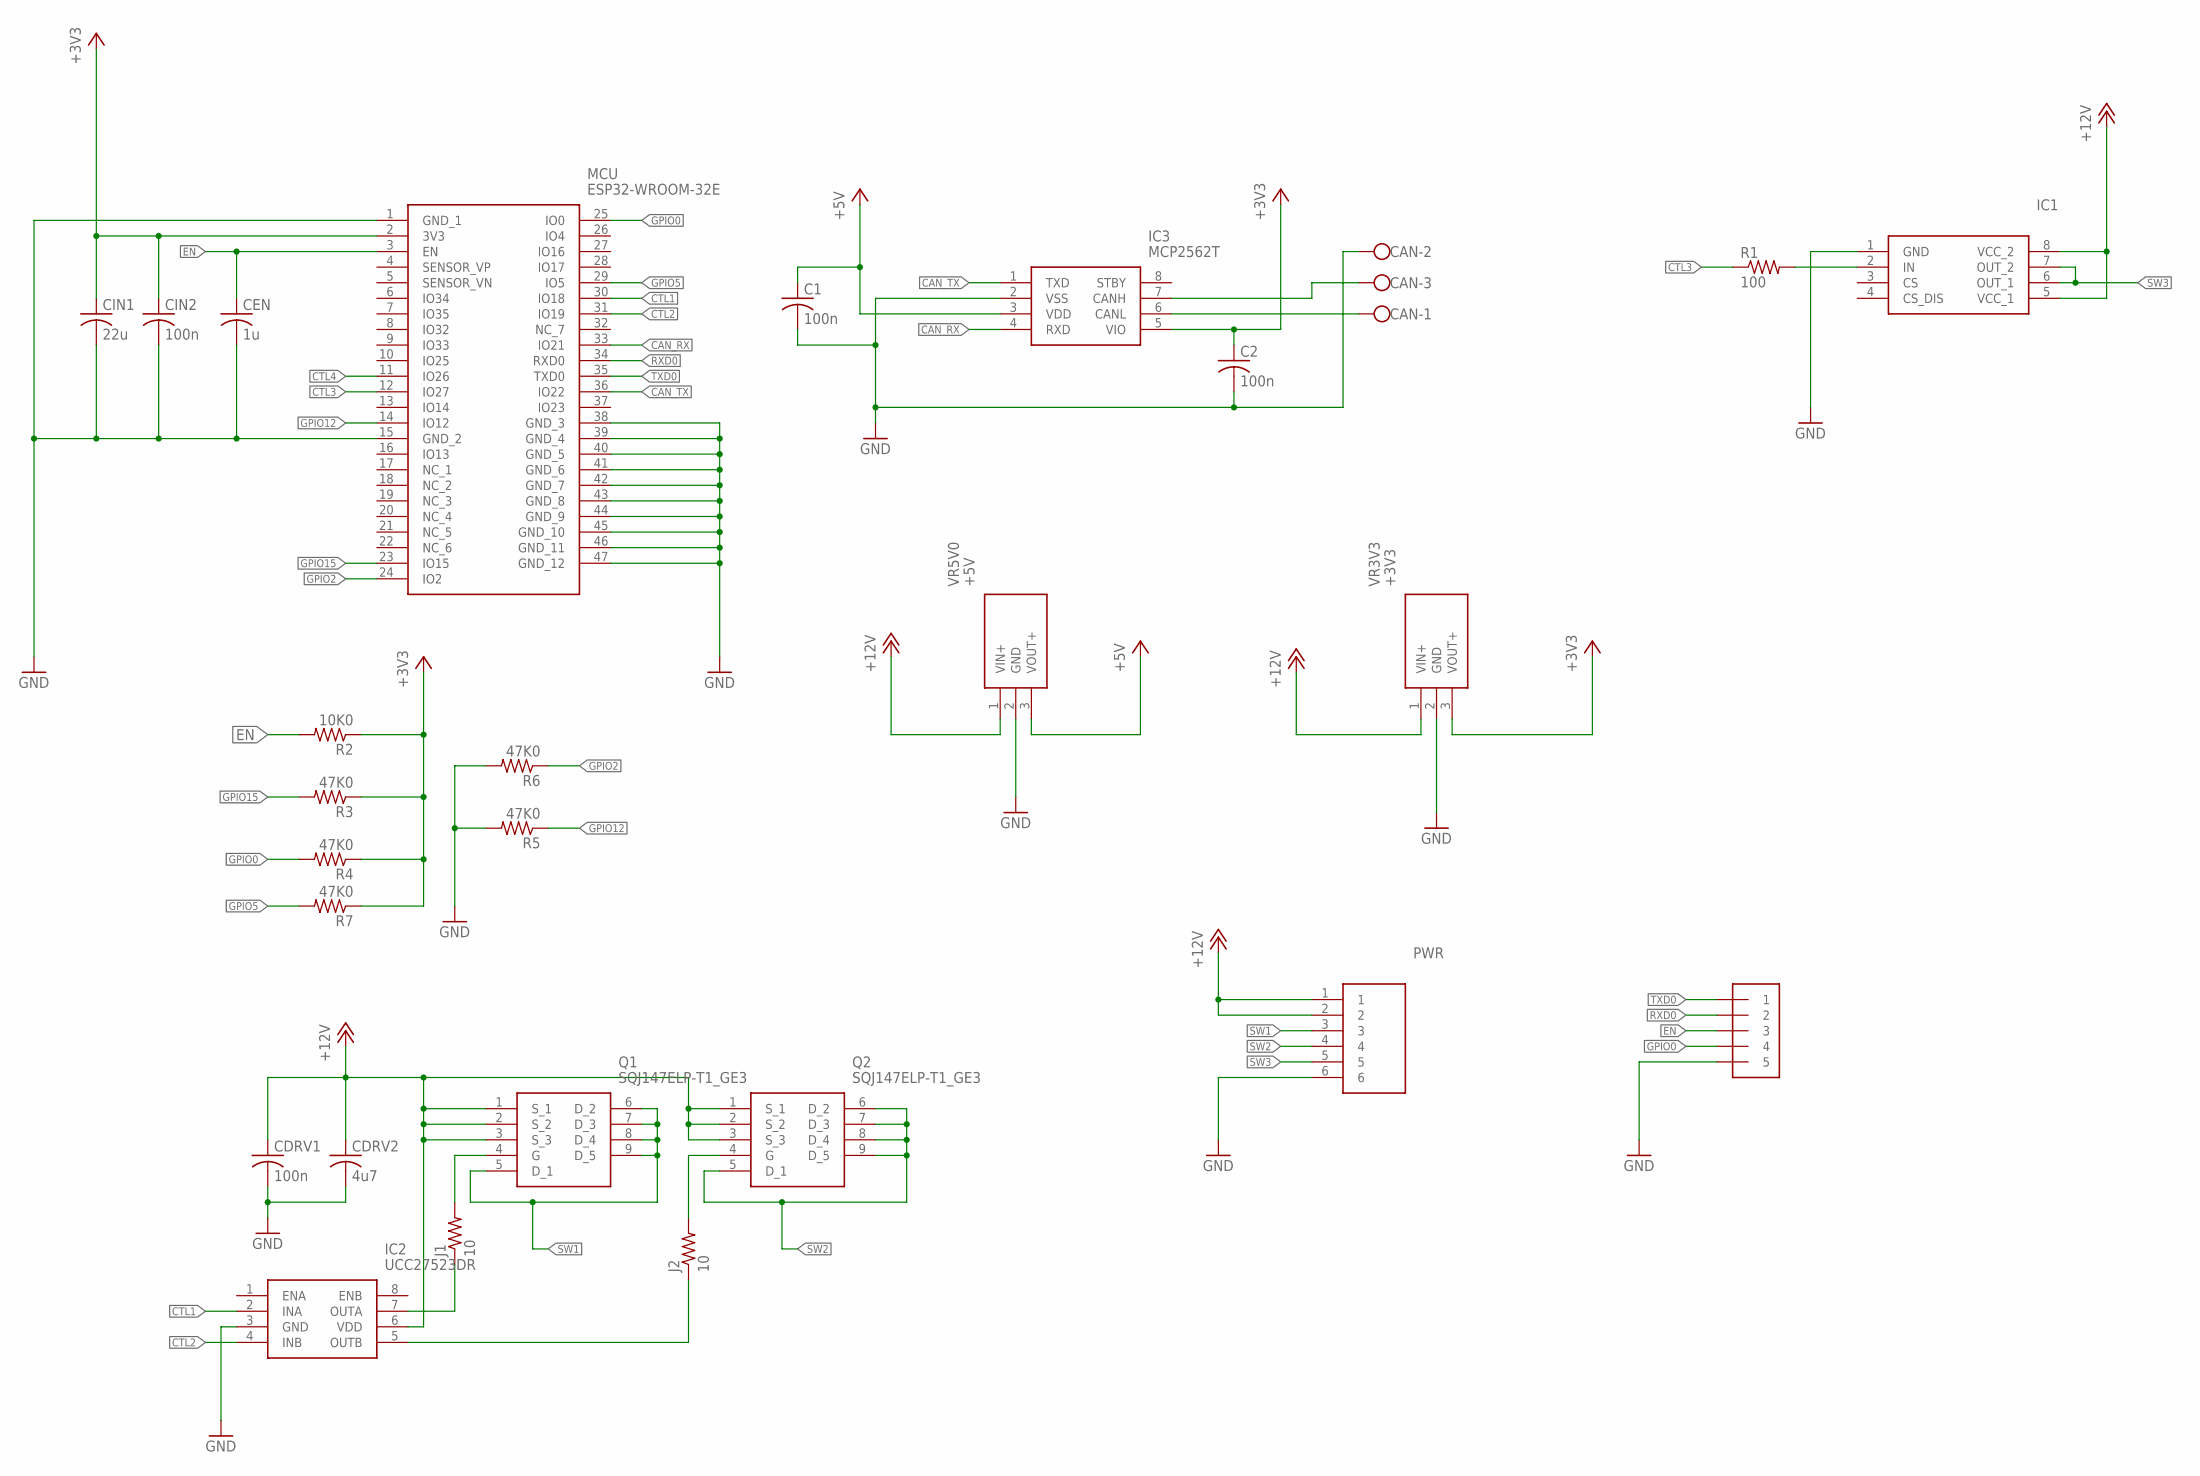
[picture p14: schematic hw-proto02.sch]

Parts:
C1, C2: 100n; C0603K
CAN: W237-103
CDRV1: 100n; C0603K
CDRV2: 4u7; C0805K
CEN: 1u; C0603K
CIN1: 22u; C0805K
CIN2: 100n; C0603K
IC1: VN5E160MSTR-E; SOIC127P600X175-8N
IC2: UCC27523DR; SOIC127P600X175-8N
IC3: MCP2562T; SOIC127P600X175-8N
J1, J2: 10; 0204/7
MCU: ESP32-WROOM-32E; ESP32WROOM32EN8R2
PROG: 1X5; 1X05-3.5MM
PWR: 4DB-P108-06; 4DBP10806
Q1, Q2: SQJ147ELP-T1_GE3; SQJ147ELPT1_GE3
R1: 100; 0204/7
R2: 10K0; R0603
R3, R4, R5, R6, R7: 47K0; R0603
VR3V3: +3V3; TSR-1-2433
VR5V0: +5V; TSR-1-2433

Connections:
+3V3: C2.1, CIN1.1, CIN2.1, IC3.5 (VIO), MCU.2 (3V3), R2.1, R3.1, R4.1, R7.1, VR3V3.3 (VOUT+)
+5V: C1.1, IC3.3 (VDD), VR5V0.3 (VOUT+)
+12V: CDRV1.1, CDRV2.1, IC1.5 (VCC_1), IC1.8 (VCC_2), IC2.6 (VDD), PWR.1, PWR.2, Q1.1 (S_1), Q1.2 (S_2), Q1.3 (S_3), Q2.1 (S_1), Q2.2 (S_2), Q2.3 (S_3), VR3V3.1 (VIN+), VR5V0.1 (VIN+)
CAN_RX: IC3.4 (RXD), MCU.33 (IO21)
CAN_TX: IC3.1 (TXD), MCU.36 (IO22)
CTL1: IC2.2 (INA), MCU.30 (IO18)
CTL2: IC2.4 (INB), MCU.31 (IO19)
CTL3: MCU.12 (IO27), R1.1
CTL4: MCU.11 (IO26)
EN: CEN.1, MCU.3 (EN), PROG.3, R2.2
GND: C1.2, C2.2, CAN.2, CDRV1.2, CDRV2.2, CEN.2, CIN1.2, CIN2.2, IC1.1 (GND), IC2.3 (GND), IC3.2 (VSS), MCU.1 (GND_1), MCU.15 (GND_2), MCU.38 (GND_3), MCU.39 (GND_4), MCU.40 (GND_5), MCU.41 (GND_6), MCU.42 (GND_7), MCU.43 (GND_8), MCU.44 (GND_9), MCU.45 (GND_10), MCU.46 (GND_11), MCU.47 (GND_12), PROG.5, PWR.6, R5.2, R6.2, VR3V3.2 (GND), VR5V0.2 (GND)
GPIO0: MCU.25 (IO0), PROG.4, R4.2
GPIO2: MCU.24 (IO2), R6.1
GPIO5: MCU.29 (IO5), R7.2
GPIO12: MCU.14 (IO12), R5.1
GPIO15: MCU.23 (IO15), R3.2
unnamed: CAN.3, IC3.7 (CANH)
unnamed: CAN.1, IC3.6 (CANL)
unnamed: IC2.5 (OUTB), J2.1
unnamed: IC2.7 (OUTA), J1.1
unnamed: J1.2, Q1.4 (G)
unnamed: J2.2, Q2.4 (G)
unnamed: IC1.2 (IN), R1.2
RXD0: MCU.34 (RXD0), PROG.2
SW1: PWR.3, Q1.5 (D_1), Q1.6 (D_2), Q1.7 (D_3), Q1.8 (D_4), Q1.9 (D_5)
SW2: PWR.4, Q2.5 (D_1), Q2.6 (D_2), Q2.7 (D_3), Q2.8 (D_4), Q2.9 (D_5)
SW3: IC1.6 (OUT_1), IC1.7 (OUT_2), PWR.5
TXD0: MCU.35 (TXD0), PROG.1

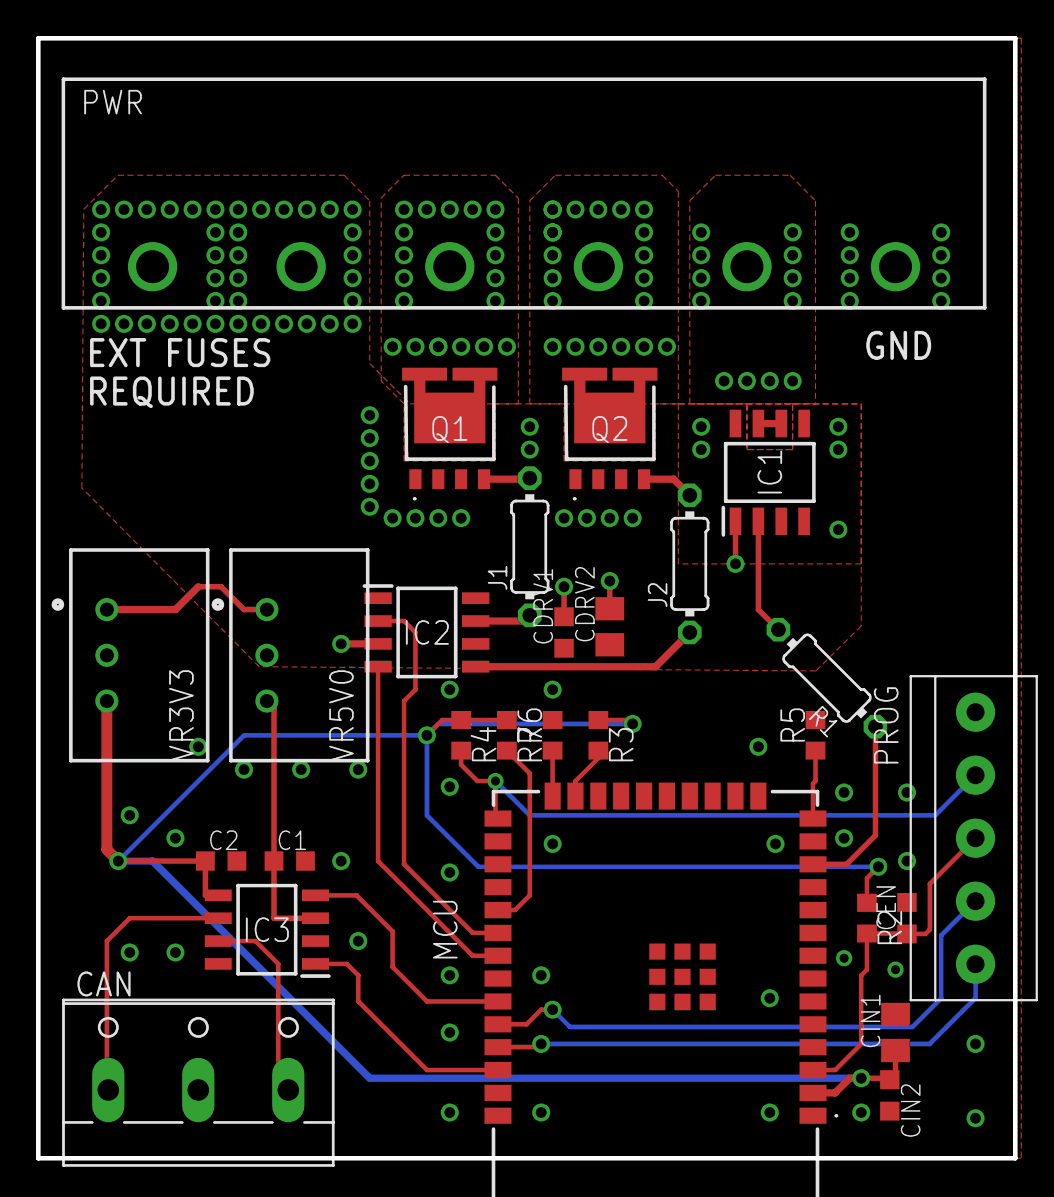
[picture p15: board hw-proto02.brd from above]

Board: 2 copper layers, 54.3 x 62.2 mm, 27 parts (0 on the bottom side), 27 nets.

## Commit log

2025-04-10 it begins
    [hw-proto01.brd, hw-proto01.sch]
2025-04-10 initial eagle drawings
    [hw-proto01.brd, hw-proto01.sch]
2025-04-10 initial drawings
    [hw-proto01.brd, hw-proto01.sch]
2025-04-11 initial layout and routing
    [hw-proto01.brd, hw-proto01.sch]
2025-04-11 need to find a better p-fet
2025-04-11 Updated board notes
2025-04-11 layout refinement, adding passives
    [hw-proto01.brd, hw-proto01.sch]
2025-04-11 duplicated project
    [hw-proto02.brd, hw-proto02.sch]
2025-04-11 changed to power-so8 fets
    [hw-proto02.brd, hw-proto02.sch]
2025-04-11 made the +12v connection more chonky
    [hw-proto02.brd, hw-proto02.sch]
2025-04-12 power layout adjustment, added passives
    [hw-proto02.brd, hw-proto02.sch]
2025-04-12 added connector library
2025-04-12 starting new layout
    [hw-proto03.brd, hw-proto03.sch]
2025-04-12 big layout - 6 switches
    [hw-proto03.brd, hw-proto03.sch]
2025-04-12 layout continues
    [hw-proto03.brd, hw-proto03.sch]
2025-04-12 2nd pass layout and routing complete, needs optimizing
    [hw-proto03.brd, hw-proto03.sch]
2025-04-12 set always vector font
    [hw-proto03.brd]
2025-04-13 layout refinement, added stiching
    [hw-proto03.brd, hw-proto03.sch]
2025-04-13 added passives, refined layout
    [hw-proto03.brd, hw-proto03.sch]
2025-04-14 added library new fet driver
2025-04-14 added link to new fet driver
2025-04-14 updated new fet driver
    [hw-proto03.brd, hw-proto03.sch]
2025-04-14 updated mosfet driver
    [hw-proto02.brd, hw-proto02.sch]
2025-04-14 grounded can connector, layout tweaks
    [hw-proto02.brd, hw-proto02.sch]
2025-04-15 added stm32 dev board
2025-04-15 added link for STM32F042C6
2025-04-15 first stm32 based design
    [hw-proto04.brd, hw-proto04.sch]
2025-04-15 swap esp32 for stm32
    [hw-proto04.brd]
2025-04-15 work on new layout
    [hw-proto04.brd, hw-proto04.sch]
2025-04-15 added stm32 datasheet
2025-04-15 schematic updates
    [hw-proto04.brd, hw-proto04.sch]
2025-04-16 layout, routing and schematic refinement
    [hw-proto04.brd, hw-proto04.sch]
2025-04-16 added VBAT divider, refinements
    [hw-proto04.brd, hw-proto04.sch]
2025-04-16 added boot0 pulldown
    [hw-proto04.brd, hw-proto04.sch]
2025-04-16 layout refinement
    [hw-proto04.brd]
2025-04-16 added term resistor, layout refinement
    [hw-proto04.brd, hw-proto04.sch]
2025-04-18 schematic refinements
    [hw-proto04.brd, hw-proto04.sch]
2025-04-18 silkscreen refinement
    [hw-proto04.brd, hw-proto04.sch]
2025-12-30 Update README
    Added a note about circuit board sketches in EagleCad.
2025-12-30 Fix typo in README.md from 'circut' to 'circuit'
2025-12-30 Updated documentation for hw-proto04
    [hw-proto04.brd, hw-proto04.sch]
2025-12-30 added pdf prints of prototype 04
2026-01-07 created a single switch demo board to eval the profet
    [hw-demo01.brd, hw-demo01.sch]
2026-01-07 add dev board pinout docu
2026-01-07 fine tune layout, add voltage regulators
    [hw-demo01.brd, hw-demo01.sch]
2026-01-08 Added details about DEMO01 board
2026-01-08 Added some power switch docu
2026-01-08 Added test points, current monitoring and a few layout refinements
    [hw-demo01.brd, hw-demo01.sch]
2026-01-08 Fix some capacitor packages and DRC errors
    [hw-demo01.brd, hw-demo01.sch]
2026-01-08 fixed board footprint for smart switch, added recommended Vs capacitor
    [hw-demo01.brd, hw-demo01.sch]
2026-01-08 adjusted board dimensions to eliminate connector overlap
    [hw-demo01.brd]
2026-01-08 tweak board dimensions
    [hw-demo01.brd]
2026-01-08 fix some via placement and drill sizes
    [hw-demo01.brd]
2026-01-08 moved the DEMO01 board to the top of the switch-board list
2026-01-08 added pcb rendering from Oshpark
2026-01-08 embedded image of pcb render
2026-01-08 layout tweak
    [hw-demo01.brd]
2026-01-09 hw demo02 board, just a switch and minimal components
    [hw-demo02.brd, hw-demo02.sch]
2026-01-09 removed unused traces and vias, layout tweaks
    [hw-demo02.brd, hw-demo02.sch]
2026-01-09 layout tweaks and layer stitching, added ground test point
    [hw-demo02.brd, hw-demo02.sch]
2026-01-09 added vias under the output pads of the switch
    [hw-demo02.brd]
2026-01-09 removed vias under switch output, added more vias around the switch output
    [hw-demo02.brd]
2026-01-09 changed layers on some signal routing
    [hw-demo02.brd]
2026-01-10 added a lot of stitching based on review of reference designs
    [hw-demo02.brd]
2026-01-10 added stitching based on review of reference designs
    [hw-demo01.brd]
2026-01-10 dual switch demo board
    [hw-demo03.brd, hw-demo03.sch]
2026-01-10 first routing pass completed
    [hw-demo03.brd, hw-demo03.sch]
2026-01-10 tweak pour for sw1
    [hw-demo03.brd]
2026-01-10 lots of ground plane and power pour stitching
    [hw-demo03.brd]
2026-01-10 add cap on voltage divider, more stitching
    [hw-demo03.brd, hw-demo03.sch]
2026-01-10 pretty happy with the layout
    [hw-demo03.brd]
2026-01-10 added rendering of the pcb
2026-01-11 added inexpensive 5v smps module to replace 5v linear
    [hw-demo03.brd, hw-demo03.sch]
2026-01-11 silkscreen tweaks
    [hw-demo03.brd]
2026-01-11 added a pour with no thermals under the switch input pad
    [hw-demo02.brd]
2026-01-11 made the 12v pour a bit wider around the input connector
    [hw-demo02.brd]

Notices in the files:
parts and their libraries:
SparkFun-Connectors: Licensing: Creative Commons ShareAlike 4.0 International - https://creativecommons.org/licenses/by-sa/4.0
